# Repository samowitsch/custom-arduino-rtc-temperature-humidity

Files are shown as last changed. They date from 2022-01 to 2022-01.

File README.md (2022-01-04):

# Custom arduino pcb with ssh1106, rtc ds3231, bme280, battery and eeprom.

> **Preface:** Dont exspect too much this is a private learning hobbyist project 😜

This is just a learning project of how to build/design a custom arduino pcb (Pro Micro) using a Atmega32U4.
The aim was to learn something about electronics and how to design a custom arduino pcb with [KiCad](https://kicad.org/).
In this repo you can find miscellaneous datasheets and schematics of other resources and the [KiCad](https://kicad.org/) files of this project itself. Included are also files for a simple case for cnc machining.

Dont expect to much of the source code (```custom-arduino-rtc-bme280.ino```). It looks a little bit messy. Uses a lot of libs and lots of ram. Improvements could be: the use of interrupts instead of a delay routine, get rid of the libs and write own code that uses less ram. In fact that i have not mounted rev1.1 there is no code for the eeprom. The eeprom could be used to store temperature data for a graph like display.

But these are future issues if I get around to it 😜

## Revisions

Rev | PCB                                          | Build
--- |----------------------------------------------| ---
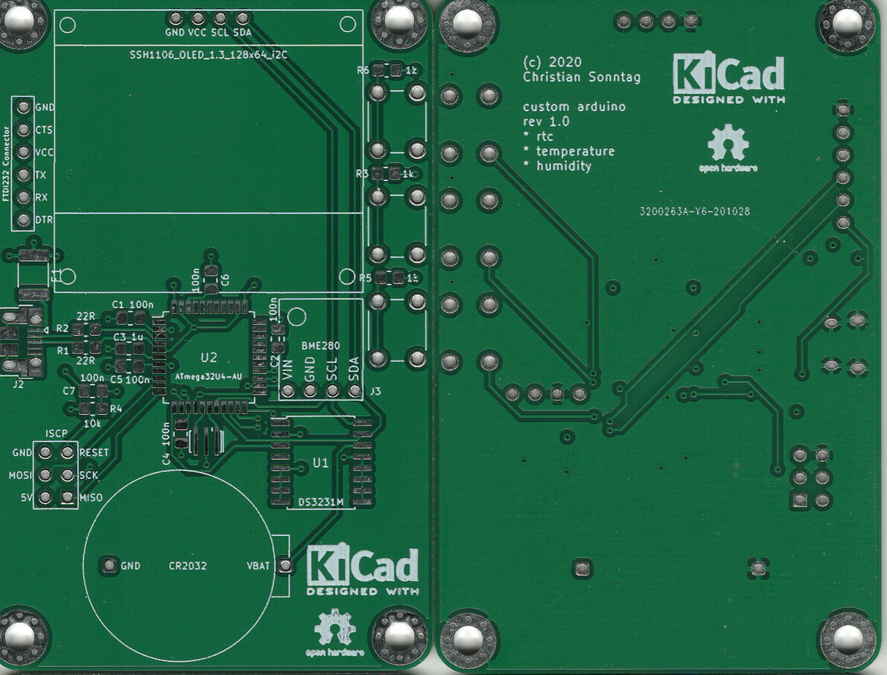
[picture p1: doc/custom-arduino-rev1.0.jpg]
pcb rev1.0
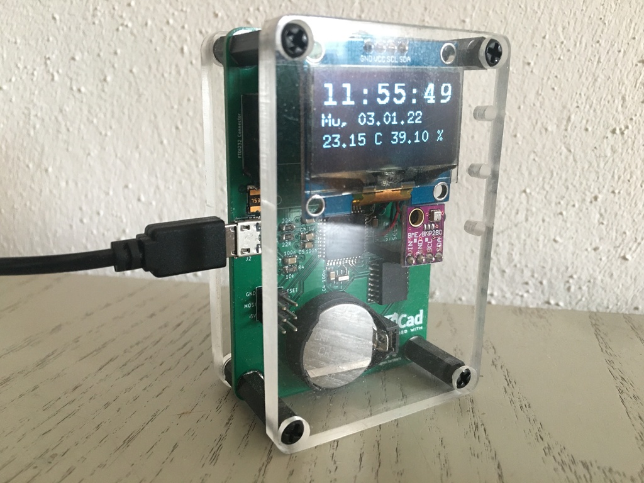
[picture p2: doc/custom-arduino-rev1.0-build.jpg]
build rev1.0
1.0 |  | 
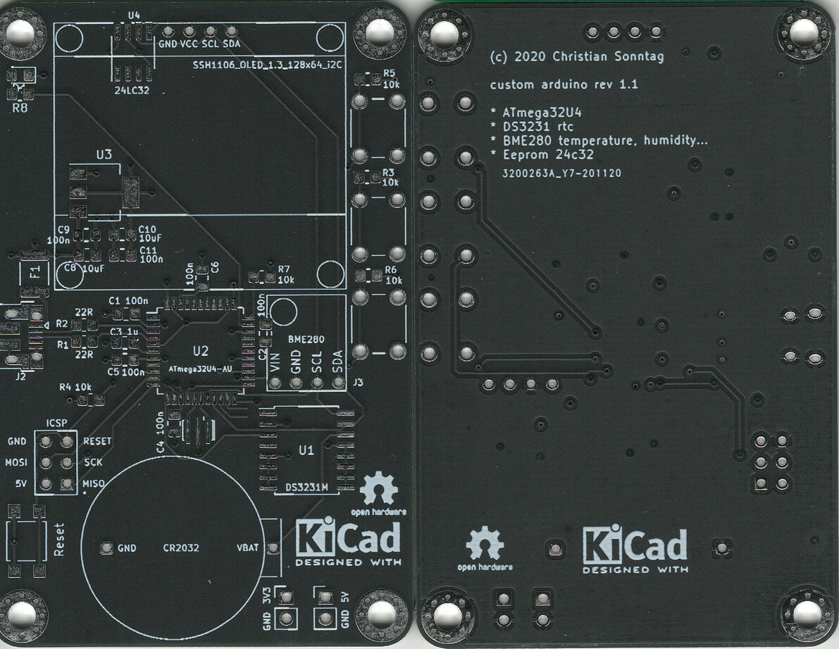
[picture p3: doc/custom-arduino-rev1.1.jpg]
pcb rev1.1
1.1 |  | not build yet ;o)

## Changes

**rev1.0**
* first layout

**rev1.1**
* [BUGFIX] connection of buttons was wrong
* [REMOVE] FTDI connector
* [ADD] eeprom
* [ADD] power led
* [ADD] reset button
* [ADD] regulator for v3.3 and pinheaders for v3.3 and v5.

## Experiences

* quality of ssh1106 lcd can be messy. thats annoying! complete pixel rows can be faulty after some period of time. 
* pin assignment of ssh1104 lcd can vary (VCC and SCL are swapped?). keep an eye on it!

---

> **Following now are some random notes!**

## Bootloader

* Burned Bootloader with USBasp programmer.
* Using SparkFun Pro Micro bootloader.
* Programming with Arduino IDE works with (Port depending to operating system):
  * SparkFun Pro Micro -> Atmega32U4 (5v, 16 MHz) -> /dev/ttyACM0

## Pin Mapping Arduino and 32u4

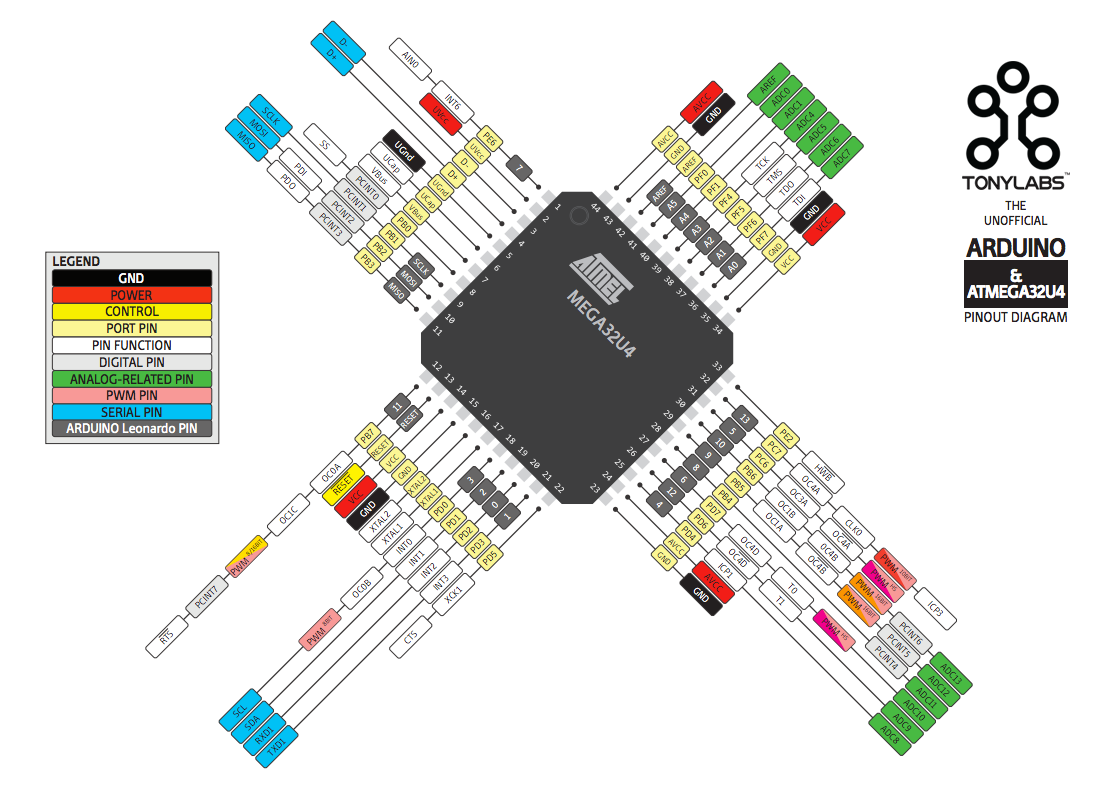
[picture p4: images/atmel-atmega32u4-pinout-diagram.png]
KiCad pcb wiring


## Arduino Pin Mapping

* https://www.arduino.cc/en/Hacking/PinMapping32u4
* https://www.arduino.cc/en/Hacking/PinMapping
* https://www.arduino.cc/en/Hacking/PinMapping168

## avrdude commands

```shell script
csg@csg-deskmini-300:~$ avrdude 
Usage: avrdude [options]
Options:
  -p <partno>                Required. Specify AVR device.
  -b <baudrate>              Override RS-232 baud rate.
  -B <bitclock>              Specify JTAG/STK500v2 bit clock period (us).
  -C <config-file>           Specify location of configuration file.
  -c <programmer>            Specify programmer type.
  -D                         Disable auto erase for flash memory
  -i <delay>                 ISP Clock Delay [in microseconds]
  -P <port>                  Specify connection port.
  -F                         Override invalid signature check.
  -e                         Perform a chip erase.
  -O                         Perform RC oscillator calibration (see AVR053). 
  -U <memtype>:r|w|v:<filename>[:format]
                             Memory operation specification.
                             Multiple -U options are allowed, each request
                             is performed in the order specified.
  -n                         Do not write anything to the device.
  -V                         Do not verify.
  -u                         Disable safemode, default when running from a script.
  -s                         Silent safemode operation, will not ask you if
                             fuses should be changed back.
  -t                         Enter terminal mode.
  -E <exitspec>[,<exitspec>] List programmer exit specifications.
  -x <extended_param>        Pass <extended_param> to programmer.
  -y                         Count # erase cycles in EEPROM.
  -Y <number>                Initialize erase cycle # in EEPROM.
  -v                         Verbose output. -v -v for more.
  -q                         Quell progress output. -q -q for less.
  -l logfile                 Use logfile rather than stderr for diagnostics.
  -?                         Display this usage.

avrdude version 6.3-20171130, URL: <http://savannah.nongnu.org/projects/avrdude/>
```
 > keep option ```-u``` ```disable safemode``` in mind when using avrdude.

Read fuses:

```avrdude -c usbasp -p m32u4 -U lfuse:r:-:h -U hfuse:r:-:h -U efuse:r:-:h -U lock:r:-:h```

Write fuse example: 

```avrdude -c usbasp -p m32u4 -U lock:w:0xEF:m```

## Tools and Sketches

* https://github.com/zkemble/AVRDUDESS
* https://github.com/nickgammon/arduino_sketches - Nick Gammon
  * Atmega board detector
  * Atmega board programmer
  * Atmega fuse calculator
  * Atmega hex uploader
  * Atmega hex uploader fixed filename
  * Atmega self read signature

## Fuse online calculators

* https://www.engbedded.com/fusecalc/
* http://eleccelerator.com/fusecalc/fusecalc.php?chip=atmega32u4

## Links

* https://lastminuteengineers.com/ - cool site with detailed information about a lot of diy modules

## Notes

### Bootloader Leonardo

```shell script
csg@csg-deskmini-300:/dev$ avrdude -c usbasp -p m32u4 

avrdude: warning: cannot set sck period. please check for usbasp firmware update.
avrdude: AVR device initialized and ready to accept instructions

Reading | ################################################## | 100% 0.00s

avrdude: Device signature = 0x1e9587 (probably m32u4)

avrdude: safemode: Fuses OK (E:CB, H:D8, L:FF)

avrdude done.  Thank you.
```

### Bootloader Sparkfun Pro Micro / ATmega32U4(5V, 16 MHz)

```shell script
csg@csg-deskmini-300:/dev$ avrdude -c usbasp -p m32u4 

avrdude: warning: cannot set sck period. please check for usbasp firmware update.
avrdude: AVR device initialized and ready to accept instructions

Reading | ################################################## | 100% 0.00s

avrdude: Device signature = 0x1e9587 (probably m32u4)

avrdude: safemode: Fuses OK (E:CB, H:D8, L:FF)

avrdude done.  Thank you.
```

# serial tests

```shell script
csg@csg-deskmini-300:/dev$ dmesg | grep tty
[    0.153752] printk: console [tty0] enabled
[    2.733836] cdc_acm 1-6:1.0: ttyACM0: USB ACM device
[45121.661109] cdc_acm 1-6:1.0: ttyACM0: USB ACM device
[46330.632603] cdc_acm 1-6:1.0: ttyACM0: USB ACM device
[46436.625977] cdc_acm 1-6:1.0: ttyACM0: USB ACM device
[46652.122351] cdc_acm 1-6:1.0: ttyACM0: USB ACM device
[47043.597710] cdc_acm 1-6:1.0: ttyACM0: USB ACM device
[47101.114440] cdc_acm 1-6:1.0: ttyACM0: USB ACM device
[47151.161149] cdc_acm 1-6:1.0: ttyACM0: USB ACM device
[47153.986526] cdc_acm 1-6:1.0: ttyACM0: USB ACM device
[47252.695573] cdc_acm 1-6:1.0: ttyACM0: USB ACM device
[47255.541345] cdc_acm 1-6:1.0: ttyACM0: USB ACM device
```

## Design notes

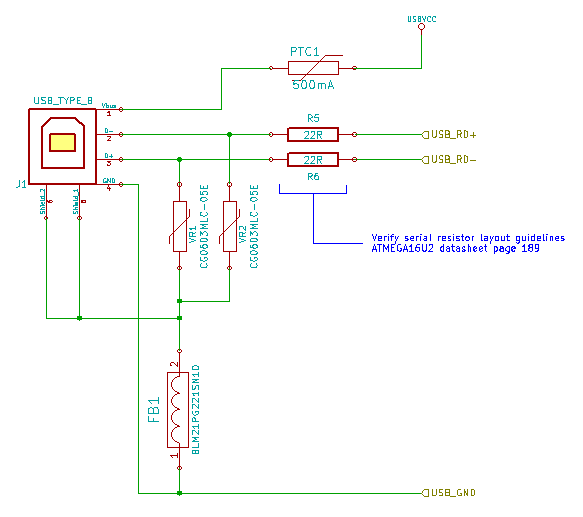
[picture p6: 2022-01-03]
research/usb-connect-schematic.png

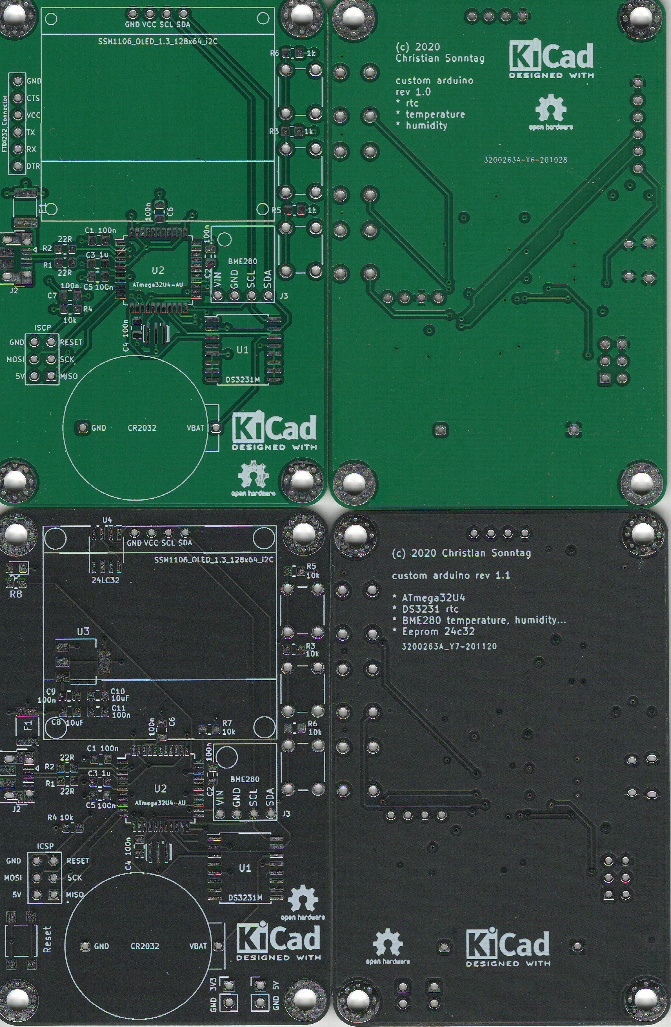
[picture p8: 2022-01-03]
doc/custom-arduino.jpg

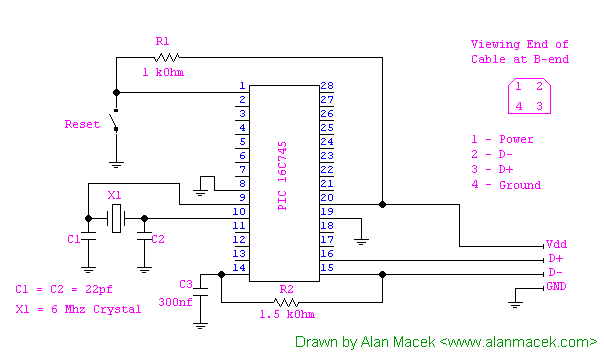
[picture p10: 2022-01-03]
research/Download (1).gif

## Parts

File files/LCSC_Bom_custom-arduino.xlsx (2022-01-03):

Quantity | Manufacture Part Number | Farnell Nr. | Beschreibung
 | ATMEGA32U4-AU | 1748525 | 8-Bit-megaAVR-Mikrocontroller mit 16MHz in TQFP-44-Bauform
 | CL21C220JBANNNC | 3010178 | Kondensator, SMD, 22 pF, 50 V, 0805 [Metrisch 2012], ± 5%, C0G / NP0, CL Series
 | CG0603MLC-05E | 1838966 | Varistor, 8 V, 5 V, Baureihe ChipGuard MLC, 20 V, 0603 [Metrisch 1608]
 | MF-MSMF050-2 | 9350314 | Rückstellbare Sicherung, PPTC, 1812 (Metrisch 4532), Baureihe MF-MSMF, 15 VDC, 500 mA, 1 A, 0.15 s
 | EA2025JA18-16.000M TR (https://de.farnell.com/ecliptek/ea2025ja18-16-000m-tr/keramikresonator-16mhz-smd/dp/3264587RL) | 3264587RL | Resonator, 16 MHz, Oberflächenmontage, 4 Pins, ± 15ppm, EA2025 Series
 | LP2985-33DBVR (https://de.farnell.com/texas-instruments/lp2985-33dbvr/ldo-fixed-3-3v-0-15a-sot-23-5/dp/3007616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) | 3007616 | LDO-Festspannungsregler, 2.2V bis 16V, 280mV Dropout, 3.3Vout, 150mAout, SOT-23-5
 | NCP1117DT50G | 2296057 | LDO-Festspannungsregler, 20Vin, 1.07V Dropout-Spannung, 5V/1Aout, TO-252-3
 | PMV48XP,215 | 1894743 | Leistungs-MOSFET, p-Kanal, 20 V, 3.5 A, 0.048 ohm, SOT-23, Oberflächenmontage
 | FDN340P | 9846310 | Leistungs-MOSFET, p-Kanal, 20 V, 2 A, 0.06 ohm, SOT-23, Oberflächenmontage
 | CD1206-S01575 | 2368400 | DIODE, ULTRAFAST RECOVERY, 150mA, 100V,
 | MH2029-300Y | 2859248 | Ferritperle, 0805 [Metrisch 2012], 30 ohm, 3 A, MH Series, 0.025 ohm, ± 25%

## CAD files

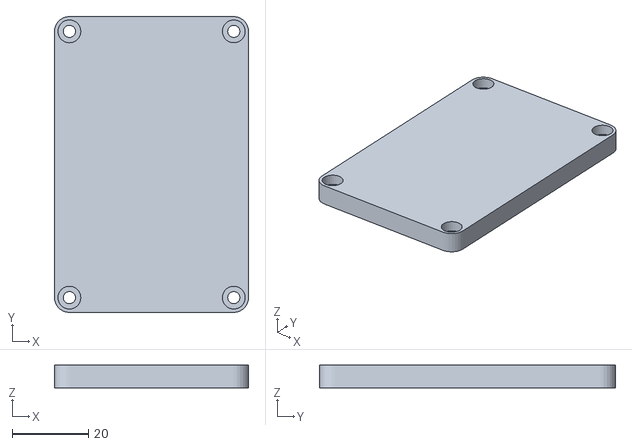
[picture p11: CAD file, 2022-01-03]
case/plate-back.stl
51.0 x 77.7 x 6.00

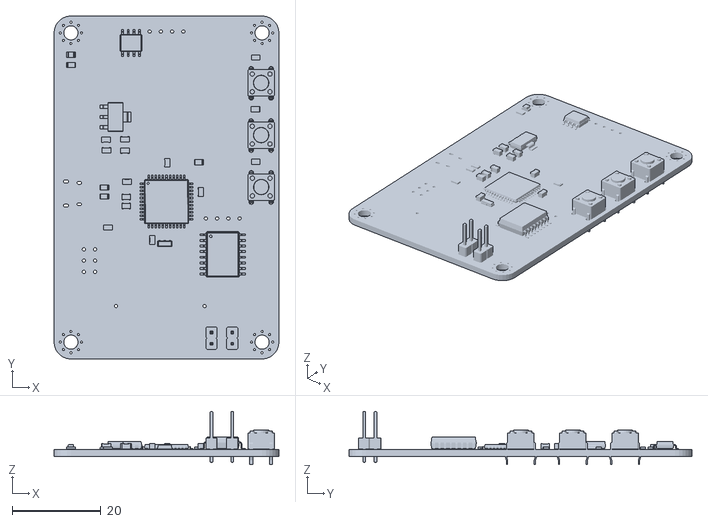
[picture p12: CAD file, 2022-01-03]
kicad/custom-arduino-rtc-temperature-humidity.stl
50.8 x 77.5 x 12.0

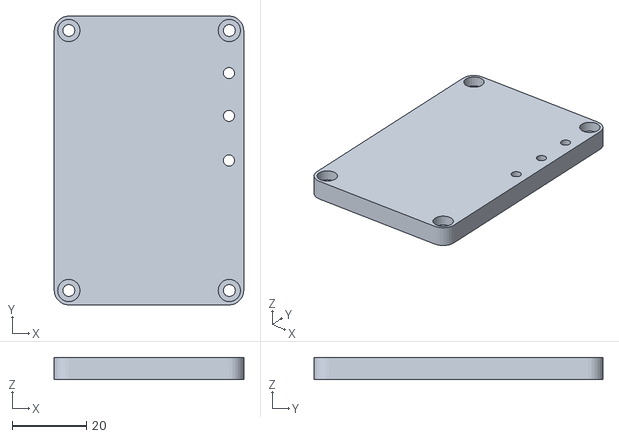
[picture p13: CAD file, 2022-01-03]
case/plate-front.stl
51.0 x 77.7 x 6.00

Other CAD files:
case/front-plate.FCStd

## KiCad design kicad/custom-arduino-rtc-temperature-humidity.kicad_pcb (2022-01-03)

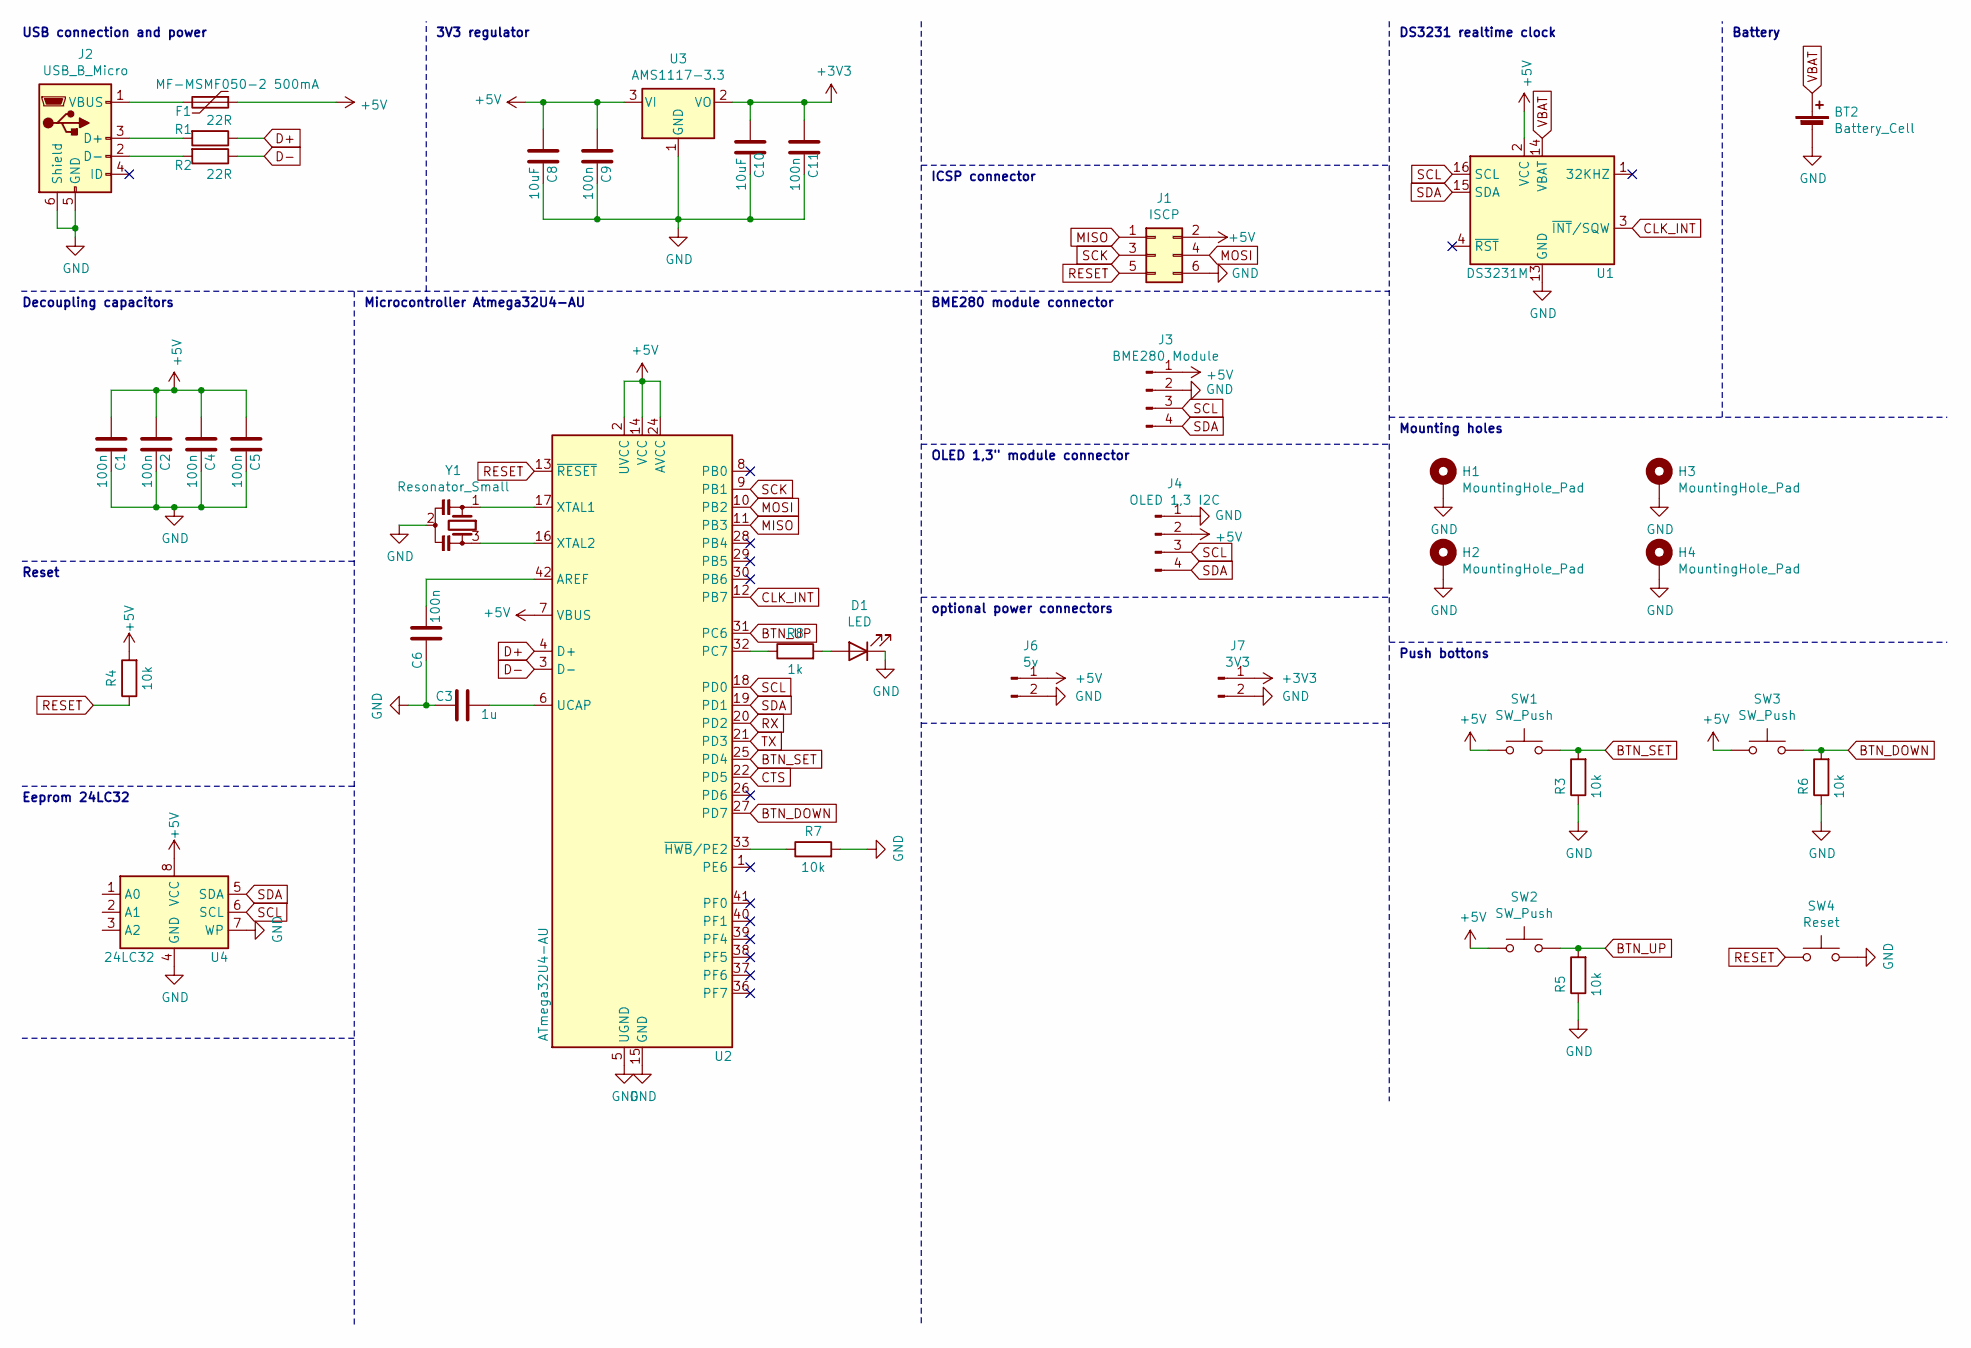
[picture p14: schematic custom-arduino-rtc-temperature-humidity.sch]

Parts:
BT2: Battery_Cell; CR2032-Battery-Holder
C1, C2, C4, C5, C6, C9, C11: 100n; C_0805_2012Metric_Pad1.18x1.45mm_HandSolder
C3: 1u; C_0805_2012Metric_Pad1.18x1.45mm_HandSolder
C8, C10: 10uF; C_0805_2012Metric_Pad1.18x1.45mm_HandSolder
D1: LED; LED_0805_2012Metric_Pad1.15x1.40mm_HandSolder
F1: MF-MSMF050-2 500mA; Fuse_1812_4532Metric_Pad1.30x3.40mm_HandSolder; Manufacturer # MF-MSMF050-2; Mouser Part # 652-MF-MSMF050-2
H1, H2, H3, H4: MountingHole_Pad; MountingHole_3.2mm_M3_Pad_Via
J1: ISCP; ICSP_Connector
J2: USB_B_Micro; USB_Micro-B_Amphenol_10103594-0001LF_Horizontal
J3: BME280 Module; BME280_Module
J4: OLED 1,3 I2C; SH1106_OLED_1.3_128x64_I2C
J6: 5v; PinHeader_1x02_P2.54mm_Vertical
J7: 3V3; PinHeader_1x02_P2.54mm_Vertical
R1, R2: 22R; R_0805_2012Metric_Pad1.20x1.40mm_HandSolder
R3, R4, R5, R6, R7: 10k; R_0805_2012Metric_Pad1.20x1.40mm_HandSolder
R8: 1k; R_0805_2012Metric_Pad1.20x1.40mm_HandSolder
SW1, SW2, SW3: SW_Push; SW_PUSH_6mm
SW4: Reset; SW_SPST_TL3305A
U1: DS3231M; SOIC-16W_7.5x10.3mm_P1.27mm; Manufacturer # DS3231M+; LCSC Part # C37663
U2: ATmega32U4-AU; TQFP-44_10x10mm_P0.8mm; Manufacturer # ATMEGA32U4-AU; LCSC Part # C44854
U3: AMS1117-3.3; SOT-223-3_TabPin2
U4: 24LC32; SOIC-8_3.9x4.9mm_P1.27mm
Y1: Resonator_Small; Resonator_SMD_muRata_CSTxExxV-3Pin_3.0x1.1mm_HandSoldering; Manufacturer # CSTNE16M0V51Z000R0; Mouser Part # 81-CSTNE16M0V51Z000R

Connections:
+3V3: C10.1, C11.1, J7.1, U3.2 (VO)
+5V: C1.1, C2.1, C4.1, C5.1, C8.1, C9.1, F1.1, J1.2, J3.1, J4.2, J6.1, R4.2, SW1.1, SW2.1, SW3.1, U1.2 (VCC), U2.2 (UVCC), U2.7 (VBUS), U2.14 (VCC), U2.24 (AVCC), U2.34 (VCC), U2.44 (AVCC), U3.3 (VI), U4.8 (VCC)
BTN_DOWN: R6.2, SW3.2, U2.27 (PD7)
BTN_SET: R3.2, SW1.2, U2.25 (PD4)
BTN_UP: R5.2, SW2.2, U2.31 (PC6)
CLK_INT: U1.3 (~INT~/SQW), U2.12 (PB7)
CTS: U2.22 (PD5)
D+: R1.1, U2.4 (D+)
D-: R2.1, U2.3 (D-)
GND: BT2.2 (-), C1.2, C2.2, C3.2, C4.2, C5.2, C6.1, C8.2, C9.2, C10.2, C11.2, D1.1 (K), H1.1, H2.1, H3.1, H4.1, J1.6, J2.5 (GND), J2.6 (Shield), J3.2, J4.1, J6.2, J7.2, R3.1, R5.1, R6.1, R7.2, SW4.2, U1.5 (GND), U1.6 (GND), U1.7 (GND), U1.8 (GND), U1.9 (GND), U1.10 (GND), U1.11 (GND), U1.12 (GND), U1.13 (GND), U2.5 (UGND), U2.15 (GND), U2.23 (GND), U2.35 (GND), U2.43 (GND), U3.1 (GND), U4.4 (GND), U4.7 (WP), Y1.2
MISO: J1.1, U2.11 (PB3)
MOSI: J1.4, U2.10 (PB2)
unnamed: C3.1, U2.6 (UCAP)
unnamed: C6.2, U2.42 (AREF)
unnamed: D1.2 (A), R8.2
unnamed: F1.2, J2.1 (VBUS)
unnamed: J2.2 (D-), R2.2
unnamed: J2.3 (D+), R1.2
unnamed: R7.1, U2.33 (~HWB~/PE2)
unnamed: R8.1, U2.32 (PC7)
unnamed: U2.16 (XTAL2), Y1.3
unnamed: U2.17 (XTAL1), Y1.1
RESET: J1.5, R4.1, SW4.1, U2.13 (~RESET)
RX: U2.20 (PD2)
SCK: J1.3, U2.9 (PB1)
SCL: J3.3, J4.3, U1.16 (SCL), U2.18 (PD0), U4.6 (SCL)
SDA: J3.4, J4.4, U1.15 (SDA), U2.19 (PD1), U4.5 (SDA)
TX: U2.21 (PD3)
VBAT: BT2.1 (+), U1.14 (VBAT)

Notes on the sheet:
Decoupling capacitors
USB connection and power
3V3 regulator
Reset
Microcontroller Atmega32U4-AU
ICSP connector
BME280 module connector
OLED 1,3" module connector
Mounting holes
DS3231 realtime clock
Battery
Push bottons
Eeprom 24LC32
optional power connectors

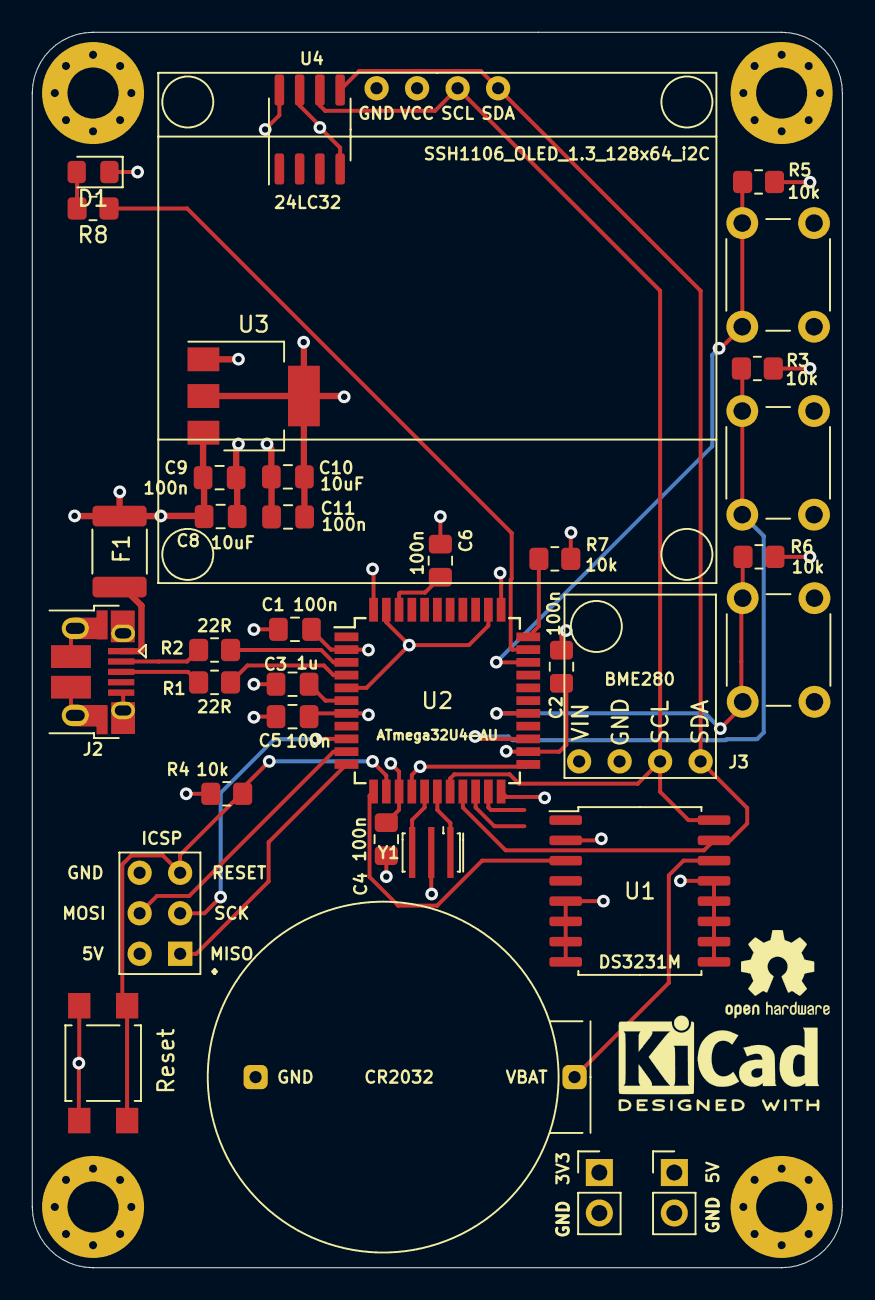
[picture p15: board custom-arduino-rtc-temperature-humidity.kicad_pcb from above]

Board: 4 copper layers, 50.8 x 77.5 mm, 40 parts (0 on the bottom side), 26 nets.

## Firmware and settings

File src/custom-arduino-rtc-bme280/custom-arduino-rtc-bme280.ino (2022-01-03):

    #include <Wire.h>
#include <EEPROM.h>
#include <BME280I2C.h>
#include <DS3231.h>
#include <EnvironmentCalculations.h>
#include "Delay.h"
#include <Bounce2.h>
#include <U8x8lib.h>

U8X8_SH1106_128X64_NONAME_HW_I2C u8x8(/* reset=*/ U8X8_PIN_NONE);

BME280I2C bme;    // Default : forced mode, standby time = 1000 ms
#define SEALEVELPRESSURE_HPA (1013.25)

float temp(NAN), hum(NAN), pres(NAN);
bool metric = true;

const char *dayName[7] = {
  "Mo", "Di", "Mi", "Do", "Fr", "Sa", "So"
};

const int SET_NONE = 0;
const int SET_HOUR = 1;
const int SET_MINUTE = 2;
const int SET_SECOND = 3;
const int SET_WEEKDAY = 4;
const int SET_DATE = 5;
const int SET_MONTH = 6;
const int SET_YEAR = 7;
int SET_CURRENT = 0;

//tmElements_t tm;
DS3231 clock;
bool century = false;
bool h12Flag;
bool pmFlag;

NonBlockDelay d;  

String temperatureTxt = "";
String delimiter = "";
String humidityTxt = "";
String pressureTxt = "";
String altitudeTxt = "";

String hoursString = "";
String minutesString = "";
String secondsString = "";

String dow = "";
String date = "";
String month = "";
String year = "";

int delayValue = 0;

const int setPin = 4;
int btnSetState = 0;
const int upPin = 5;
int btnUpState = 0;
const int downPin = 6;
int btnDownState = 0;

Bounce btnSet = Bounce();
Bounce btnUp = Bounce();
Bounce btnDown = Bounce();

struct MyObject{
  float field1;
  byte field2;
  char name[10];
};

void setup() {
  Serial.begin(115200);
  
  //float f = 0.00f;   //Variable to store data read from EEPROM.
  //int eeAddress = 0; //EEPROM address to start reading from
  
  pinMode(setPin, INPUT);
  pinMode(upPin, INPUT);
  pinMode(downPin, INPUT);
  pinMode(LED_BUILTIN, OUTPUT);

  btnSet.attach(setPin, INPUT_PULLUP);
  btnSet.interval(25);
  btnUp.attach(upPin, INPUT_PULLUP);
  btnUp.interval(25);
  btnDown.attach(downPin, INPUT_PULLUP);
  btnDown.interval(25);

  u8x8.begin();
  u8x8.setPowerSave(0);
  
/*
  Serial.print( "Read float from EEPROM: " );

  //Get the float data from the EEPROM at position 'eeAddress'
  EEPROM.get( eeAddress, f );
  Serial.println( f, 3 );  //This may print 'ovf, nan' if the data inside the EEPROM is not a valid float.

  // get() can be used with custom structures too.
  eeAddress = sizeof(float); //Move address to the next byte after float 'f'.
  MyObject customVar; //Variable to store custom object read from EEPROM.
  EEPROM.get( eeAddress, customVar );

  Serial.println( "Read custom object from EEPROM: " );
  Serial.println( customVar.field1 );
  Serial.println( customVar.field2 );
  Serial.println( customVar.name );
*/

  while (!bme.begin())
  {
    u8x8.drawString(0, 0, "BME280 sensor!?");
    delay(1000);
  }

  Serial.println( "Setup done!?");
}

void drawString(int x, int y, char *str, int setmode = SET_NONE, int font = u8x8_font_8x13_1x2_r) {
      u8x8.setFont(font);
      if (setmode > SET_NONE && setmode == SET_CURRENT) {
        u8x8.setInverseFont(1);
        u8x8.drawString(x, y, str);
        u8x8.setInverseFont(0);
      } else {
        u8x8.drawString(x, y, str);
      }
}

String padLeft(String str) {
  if (str.length() < 2) {
    str = "0" + str;
  }
  return str;
}

void updateRTC(int val) {
  if (SET_CURRENT == 0) {
    return;
  }
  if(SET_CURRENT == SET_HOUR){
      int hour = clock.getHour(h12Flag, pmFlag);
      //Serial.println("update hour " + String(hour));
      hour += val;
      if (hour > 23) {
        hour = 0;
      }
      if (hour < 0) {
        hour = 23;
      }
      //Serial.println("update hour new value " + String(hour));
      clock.setHour(hour);
  } else if (SET_CURRENT == SET_MINUTE) {
      int minute = clock.getMinute();
      //Serial.println("update minute " + String(minute));
      minute += val;
      if (minute > 59) {
        minute = 0;
      }
      if (minute < 0) {
        minute = 59;
      }
      //Serial.println("update minute new value" + String(minute));
      clock.setMinute(minute);   
  } else if (SET_CURRENT == SET_SECOND) {
      int second = clock.getSecond();
      //Serial.println("update second " +String(second));
      second += val;
      if (second > 59) {
        second = 0;
      }
      if (second < 0) {
        second = 59;
      }
      //Serial.println("update second " + String(second));
      clock.setSecond(second);
  } else if (SET_CURRENT == SET_WEEKDAY) {
      int day = clock.getDoW();
      //Serial.println("update weekday " + String(day));
      day += val;
      if (day > 7) {
        day = 1;
      }
      if (day < 1) {
        day = 7;
      }
      //Serial.println("update weekday new value " + String(day));
      clock.setDoW(day);
 } else if (SET_CURRENT == SET_DATE){
      int date = clock.getDate();
      //Serial.println("update date " + String(date));
      date += val;
      if (date > 31) {
        date = 1;
      }
      if (date < 1) {
        date = 31;
      }
      //Serial.println("update date new value " + String(date));
      clock.setDate(date);
  } else if (SET_CURRENT == SET_MONTH) {
      int month = clock.getMonth(century);
      //Serial.println("update month " + String(month));
      month += val;
      if (month > 12) {
        month = 1;
      }
      if (month < 1) {
        month = 12;
      }
      //Serial.println("update month new value " + String(month));
      clock.setMonth(month);
  } else if (SET_CURRENT == SET_YEAR) {
      int year = clock.getYear();
      //Serial.println("update year " + String(year));
      year += val;
      //Serial.println("update year new value " + String(year));
      clock.setYear(year);
  }
}

void loop() {
  btnSet.update();
  btnUp.update();
  btnDown.update();

  if(Serial.available() > 0){
    char data = Serial.read(); // Reading Serial Data and saving in data variable
    Serial.print(data); // Printing the Serial data
    Serial.println("");
  }
  

  if (btnSet.fell()) {
    delayValue = 0;
    SET_CURRENT++;
    if (SET_CURRENT > 7 ) {
      SET_CURRENT = 0;
    }
    //Serial.println("set button: " + String(SET_CURRENT));
  }

  if (btnUp.fell()) {
    //Serial.println("up button");
    updateRTC(1);
    delayValue = 0;
  }

  if (btnDown.fell()) {
    //Serial.println("down button");
    updateRTC(-1);
    delayValue = 0;
  }

  if(d.Timeout()){ 
    hoursString = padLeft(String(clock.getHour(h12Flag, pmFlag)));
    minutesString = padLeft(String(clock.getMinute()));
    secondsString = padLeft(String(clock.getSecond()));

    drawString(0, 0, hoursString.c_str(), SET_HOUR, u8x8_font_courB18_2x3_n);
    drawString(4, 0, ":", SET_NONE, u8x8_font_courB18_2x3_n);
    drawString(6, 0, minutesString.c_str(), SET_MINUTE, u8x8_font_courB18_2x3_n);
    drawString(10, 0, ":", SET_NONE, u8x8_font_courB18_2x3_n);
    drawString(12, 0, secondsString.c_str(), SET_SECOND, u8x8_font_courB18_2x3_n); 


    if (delayValue >= 30 || delayValue == 0) {
      dow = String(dayName[clock.getDoW() - 1]);
      date = padLeft(String(clock.getDate()));
      month = padLeft(String(clock.getMonth(century)));
      year = String(clock.getYear());
      
      BME280::PresUnit presUnit(BME280::PresUnit_Pa);
      BME280::TempUnit tempUnit(BME280::TempUnit_Celsius);

      bme.read(pres, temp, hum, tempUnit, presUnit);
    
      float altitude = EnvironmentCalculations::Altitude(pres, metric);

      temperatureTxt = String(temp) + " C";
      humidityTxt = String(hum) + " %";
            
      delayValue = 1;
      drawString(0, 3.5, dow.c_str(), SET_WEEKDAY);
      drawString(2, 3.5, ",");
      drawString(4, 3.5, date.c_str(), SET_DATE);
      drawString(6, 3.5, ".");
      drawString(7, 3.5, month.c_str(), SET_MONTH);
      drawString(9, 3.5, ".");
      drawString(10, 3.5, year.c_str(), SET_YEAR);
      
      u8x8.drawString(0, 5, temperatureTxt.c_str());
      u8x8.drawString(8, 5, humidityTxt.c_str());
    }
    if (SET_CURRENT != SET_NONE) {
      d.Delay(25);
      return;
    }
    delayValue++;

    
    d.Delay(1000);
  }
}

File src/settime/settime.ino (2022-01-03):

// DS1307RTC - Version: 1.4.1

#include <Wire.h>
#include <TimeLib.h>
#include <DS1307RTC.h>

const char *monthName[12] = {
  "Jan", "Feb", "Mar", "Apr", "May", "Jun",
  "Jul", "Aug", "Sep", "Oct", "Nov", "Dec"
};

tmElements_t tm;

void setup() {
  bool parse=false;
  bool config=false;

  // get the date and time the compiler was run
  if (getDate(__DATE__) && getTime(__TIME__)) {
    parse = true;

    // Mon = 1, Tue = 2, Whe = 3, Thu = 5, Fr = 5, Sat = 6, Sun = 7
    tm.Wday = 5;
    // and configure the RTC with this info
    if (RTC.write(tm)) {
      config = true;
    }
  }

  Serial.begin(57600);
  while (!Serial) ; // wait for Arduino Serial Monitor

  Serial.print("__DATE__ :");
  Serial.println(__DATE__);
  Serial.print("__TIME__ :");
  Serial.println(__TIME__);

  delay(200);
  if (parse && config) {
    Serial.print("DS1307 configured Time=");
    Serial.print(__TIME__);
    Serial.print(", Date=");
    Serial.println(__DATE__);
  } else if (parse) {
    Serial.println("DS1307 Communication Error :-{");
    Serial.println("Please check your circuitry");
  } else {
    Serial.print("Could not parse info from the compiler, Time=\"");
    Serial.print(__TIME__);
    Serial.print("\", Date=\"");
    Serial.print(__DATE__);
    Serial.println("\"");
  }
}

void loop() {
}

bool getTime(const char *str)
{
  int Hour, Min, Sec;

  if (sscanf(str, "%d:%d:%d", &Hour, &Min, &Sec) != 3) return false;
  tm.Hour = Hour;
  tm.Minute = Min;
  tm.Second = Sec;
  return true;
}

bool getDate(const char *str)
{
  char Month[12];
  int Day, Year;
  uint8_t monthIndex;

  if (sscanf(str, "%s %d %d", Month, &Day, &Year) != 3) return false;
  for (monthIndex = 0; monthIndex < 12; monthIndex++) {
    if (strcmp(Month, monthName[monthIndex]) == 0) break;
  }
  if (monthIndex >= 12) return false;
  tm.Day = Day;
  tm.Month = monthIndex + 1;
  tm.Year = CalendarYrToTm(Year);
  return true;
}

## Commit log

2022-01-04 fix KiCad link
2026-01-11 research more example schematics

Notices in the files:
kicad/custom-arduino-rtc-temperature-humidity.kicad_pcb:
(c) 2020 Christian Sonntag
